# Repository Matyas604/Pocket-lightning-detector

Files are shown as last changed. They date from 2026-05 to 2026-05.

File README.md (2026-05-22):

# Pocket lightning detector
A while back, I was browsing websites with various components and modules when a lightning sensor cought my eye. I was really curious about how it works, so I started researching it. After watching a few Youtube videos 
about this module, I decided I had to try it out. Then I started thinking, and suddenly occurred to me that it would be really cool to create a small, portable, battery-powered device that fits in your pocket and detect 
lightnings. So why not? Why not just design my own PCB and build the entire device myself?

I really enjoyd this project because I tried out a lot of different thigs: studying datasheets and schematics, searching for and creating my own schematic, and designing the PCB and case.

## Features
- The entire device is powered by a **Li-Po** rechargeable battery
- It uses the [**ESP-C3-MINI**](https://documentation.espressif.com/esp32-c3-mini-1_datasheet_en.pdf) as the main microcontroller
- Has **USB-C** port for programming and charging the device
- [**AS3935**](https://www.laskakit.cz/user/related_files/as3935_datasheet.pdf) and **MA5532-AE** for lightning detection
- Detects lightning strikes up to **40 km** away
- Records the distance, energy and current time of lightning strike
- Everything is stored in the internal **RTC memory**, which can store up to 50 lightnings strikes
- Communicates with a mobile via **Bluetooth** to synchronize the time and data
- Has audio feedback when a lightning strike been detected or other thing happened
- Various battery protections, such as **overcharge**, **undercharge**, **over-discharge** and **overvoltage**
- It uses deep sleep mode to get the longest possible battery life

## CAD model
Everything is stored in a case consisting of two parts: a base and a top cover. The top cover is secured with four **M3** screws and heat inserts, along with the **PCB**, which is secured with two screws. The buttons are labeled
with icons for clear identification of their functions. The dimensions are 106 mm in length, 60 mm in width, and 35 mm in height.

<p align="center">
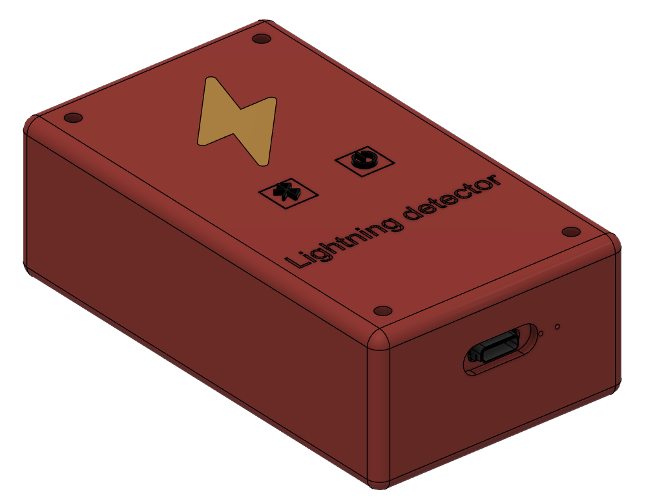
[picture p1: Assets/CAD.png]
CAD model
  
</p>
<p align="center">
  <strong>Made in Fusion360</strong>
</p>

## PCB
It includes two switches: one to turn on and of the device and other to activate **Bluetooth**. In the upper right corner, above the **USB-C** port, are chips for charging, protection, monitoring, and drawing power from the battery, there is also a connector for the battery. The lightning sensor communicates via **I2C**. The pull-up resistors are located under the **ESP-32** near the edge of the **PCB**. The dimensions of **PCB** are 99.7 mm x 35 mm.

<p align="center">
  Schematic
</p>
<p align="center">
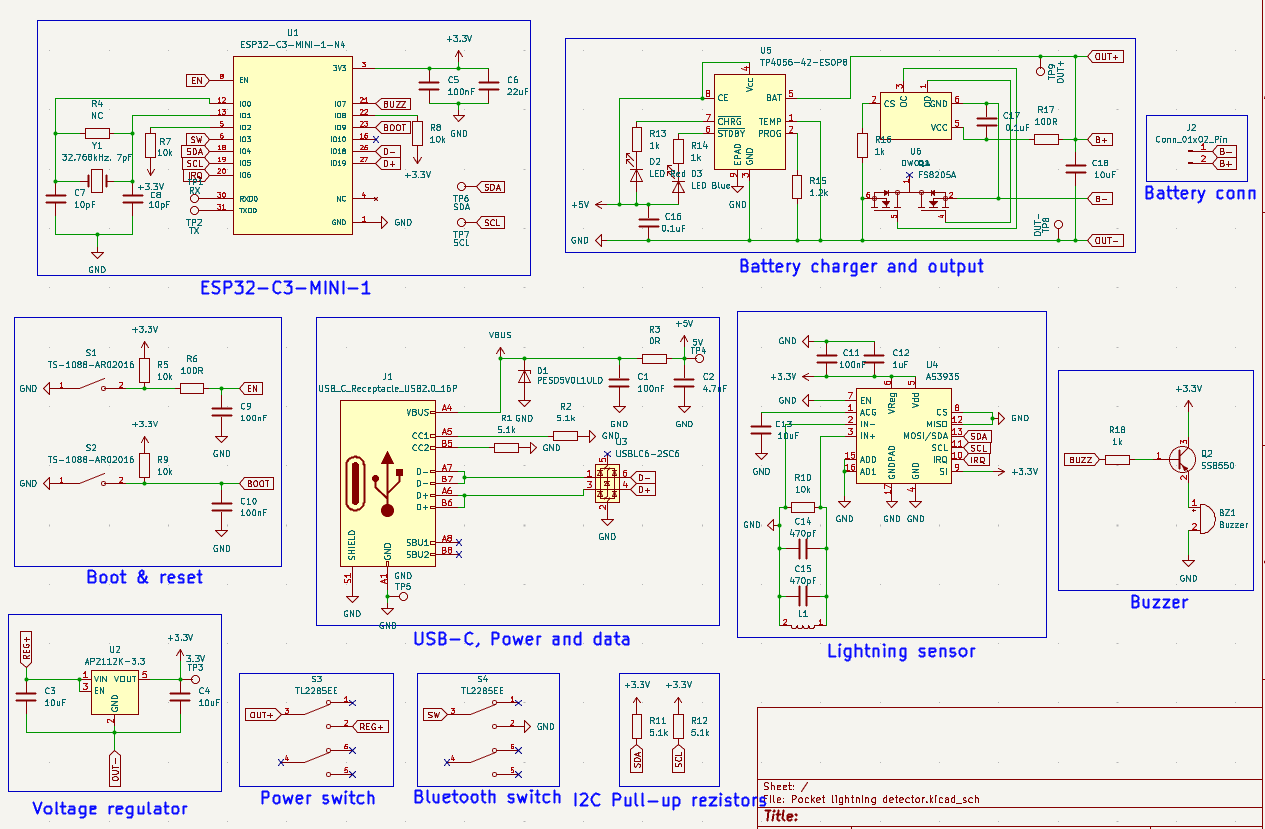
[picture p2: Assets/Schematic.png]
PCB schematic
  
</p>
<p align="center">
  PCB
</p>
<p align="center">
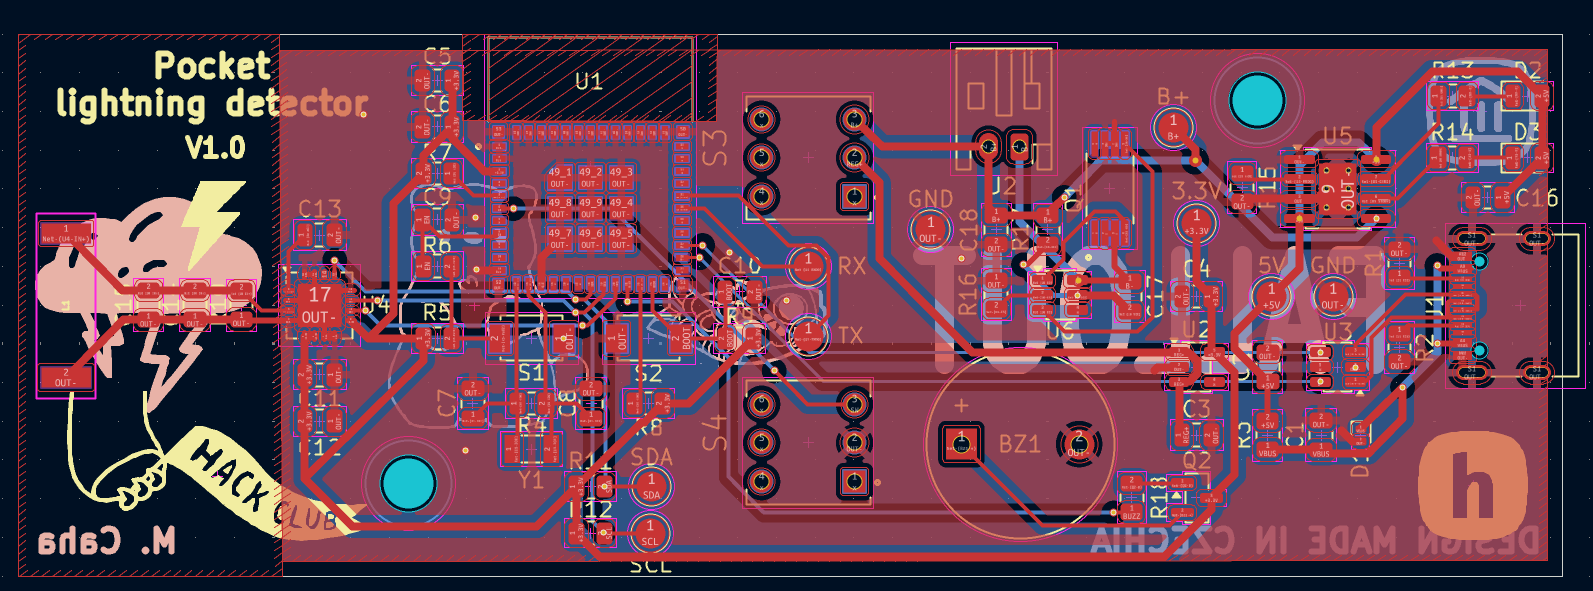
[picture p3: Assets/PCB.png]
  
</p>
<p align="center">
  <strong>Made in KiCad</strong>
</p>
⚠️ The area around the lightning sensor antenna must be kept sufficiently far away from metal parts, as there could interfere with the antenna. For this reason, there si no GND copper area around it, and no screws are located nerby.

## Poster
<p align="center">
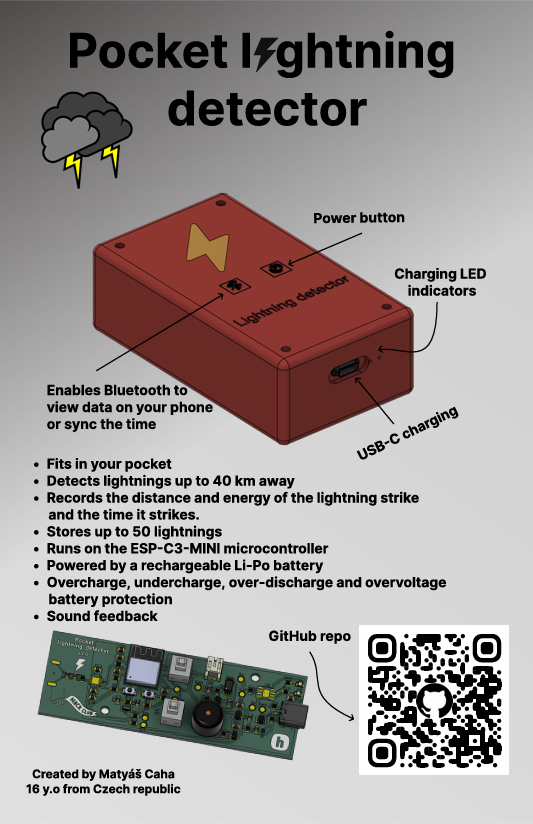
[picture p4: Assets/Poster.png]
  
</p>
<p align="center">
  <strong>Made in Figma</strong>
</p>

## Firmware
It uses standard **C++** code. One button turns the device on, and the other activates **Bluetooth** to display lightnings data and synchronize the time. The time must be synchronized every time the device is turned on. Data cen be currently displayed via a serial monitor application. Once the device is connected, it automatically sends lightning data every 3 seconds. Time is synchronized by sending a command, and the board then retrieves the current time. Lightning strikes and the time are stored in **RTC memory**, so they are erased when the device is turned off. The device runs continuously in deep sleep mode and wakes up only when a lightning strike occurs to save data about the strike and the time it happened, then goes back into deep sleep. **RTC memory** is the only component that remains active even when the device is in deep sleep mode. The **RTC memory** stores a maximum of the last **50 lightning strikes** to prevent it from becoming overloaded. My goal was to maximize battery life, so I chose **Bluetooth** over **Wi-Fi** because **Bluetooth** is much more power-efficient, and I use deep sleep mode as well (Once the device is finished, I’ll carefully measure its battery life).  You can found further details in the comments within the code. After i finished the device, I’ll probably create a nice app where the lightnings will be saved and can be viewed back in time. 

## BOM
You can find it in .csv format [here](https://github.com/Matyas604/Pocket-lightning-detector/blob/main/BOM.csv). 

## License
This project is licensed under the GNU GPL v3.
```
Matyas604/Pocket-lightning-detector - Battery-powered Pocket Lightning Detector
Copyright (C) 2026 Matyáš Caha

This program is free software: you can redistribute it and/or modify
it under the terms of the GNU General Public License as published by
the Free Software Foundation, either version 3 of the License, or
(at your option) any later version.

This program is distributed in the hope that it will be useful,
but WITHOUT ANY WARRANTY; without even the implied warranty of
MERCHANTABILITY or FITNESS FOR A PARTICULAR PURPOSE. See the
GNU General Public License for more details.

You should have received a copy of the GNU General Public License
along with this program. If not, see <https://www.gnu.org/licenses/>.
```

<hr>

<p align="center">
  Made with ❤️ by <a href="https://github.com/Matyas604">@Matyas604</a>
</p>

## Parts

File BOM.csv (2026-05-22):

Item | Qty. | Price (USD) | Link | Distributor
PCB | 1 | 2 | https://jlcpcb.com/ | JLCPCB
Stencil | 1 | 3.05 | https://jlcpcb.com/ | JLCPCB
JLCPCB Shipping | 1 | 11.80 | https://jlcpcb.com/ | JLCPCB
ESP32-C3-MINI-1-N4 | 1 | 3.15 | https://www.lcsc.com/product-detail/C2838502.html | LCSC
CC0805KRX7R9BB104 | 6 | 0.53 | https://www.lcsc.com/product-detail/C49678.html | LCSC
CL21A226KOQNNNE | 1 | 0.6 | https://www.lcsc.com/product-detail/C296720.html | LCSC
GRM21BR71H105KA12L | 1 | 0.77 | https://www.lcsc.com/product-detail/C77083.html | LCSC
GRM21BR61H106KE43L | 4 | 0.69 | https://www.lcsc.com/product-detail/C440198.html | LCSC
VJ0805A471FXACW1BC | 2 | 1.47 | https://www.lcsc.com/product-detail/C1850692.html | LCSC
FRC0805F1002TS | 4 | 0.2 | https://www.lcsc.com/product-detail/C2907219.html | LCSC
FRC0805F1001TS | 4 | 0.2 | https://www.lcsc.com/product-detail/C2907232.html | LCSC
FRC0805F1201TS | 1 | 0.2 | https://www.lcsc.com/product-detail/C2933293.html | LCSC
RC0805FR-07100RL | 2 | 0.27 | https://www.lcsc.com/product-detail/C105577.html | LCSC
0805W8F5101T5E | 4 | 0.27 | https://www.lcsc.com/product-detail/C27834.html | LCSC
0805W8F0000T5E | 1 | 0.23 | https://www.lcsc.com/product-detail/C17477.html | LCSC
USBLC6-2SC6 | 1 | 0.76 | https://www.lcsc.com/product-detail/C7519.html | LCSC
PESD5V0L1ULD | 1 | 0.45 | https://www.lcsc.com/product-detail/C552557.html | LCSC
TYPE-C-31-M-12 | 1 | 0.86 | https://www.lcsc.com/product-detail/C165948.html?s_z=n_C165948 | LCSC
AP2112K-3.3 | 1 | 0.82 | https://www.lcsc.com/product-detail/C51118.html | LCSC
TS-1088-AR02016 | 2 | 0.54 | https://www.lcsc.com/product-detail/C720477.html | LCSC
TP4056-42-ESOP8 | 1 | 0.93 | https://www.lcsc.com/product-detail/C16581.html | LCSC
DW01A | 1 | 0.86 | https://www.lcsc.com/product-detail/C351410.html | LCSC
FS8205A | 1 | 0.47 | https://www.lcsc.com/product-detail/C2830320.html | LCSC
SS8550 | 1 | 0.52 | https://www.lcsc.com/product-detail/C727138.html | LCSC
2.54-1*20P | 1 | 0.69 | https://www.lcsc.com/product-detail/C50981.html | LCSC
S2B-PH-K-S(LF)(SN) | 1 | 0.76 | https://www.lcsc.com/product-detail/C173752.html | LCSC
YLED0805B | 1 | 0.84 | https://www.lcsc.com/product-detail/C19273154.html | LCSC
YLED0805R | 1 | 0.81 | https://www.lcsc.com/product-detail/C19171391.html | LCSC
3131M-32.768DT07NNL | 1 | 0.89 | https://www.lcsc.com/product-detail/C46598421.html | LCSC
VJ0805A100FXACW1BC | 2 | 0.94 | https://www.lcsc.com/product-detail/C2177610.html | LCSC
CL21A475KBQNNNE | 1 | 0.27 | https://www.lcsc.com/product-detail/C98192.html | LCSC
LCSC Shipping | 1 | 10.45 | https://www.lcsc.com/ | LCSC
103040 3.7v 1200mAh Li-ion Battery | 1 | 5.91 | https://www.aliexpress.com/item/1005007995684160.html | AliExpress
Passive Buzzer | 1 | 2.26 | https://www.aliexpress.com/item/1005007144511679.html | AliExpress
Button Switches 8x8 | 2 | 1.97 | https://www.aliexpress.com/item/32874871399.html | AliExpress
M3 4mm | 2 | 2.55 | https://www.aliexpress.com/item/4000981220901.html | AliExpress
M3 6mm | 4 | 2.52 | https://www.aliexpress.com/item/4000981220901.html | AliExpress
M3 heat inserts | 6 | 2.87 | https://www.aliexpress.com/item/1005008666672949.html | AliExpress
3D parts | 5 | 7 | Printing legion | Hack club
AS3935 and MA5532-AE | 1 | 21.83 | https://www.aliexpress.com/item/32828658129.html | AliExpress
AliExpress Shipping | 1 | 1.71 | https://www.aliexpress.com/ | AliExpress

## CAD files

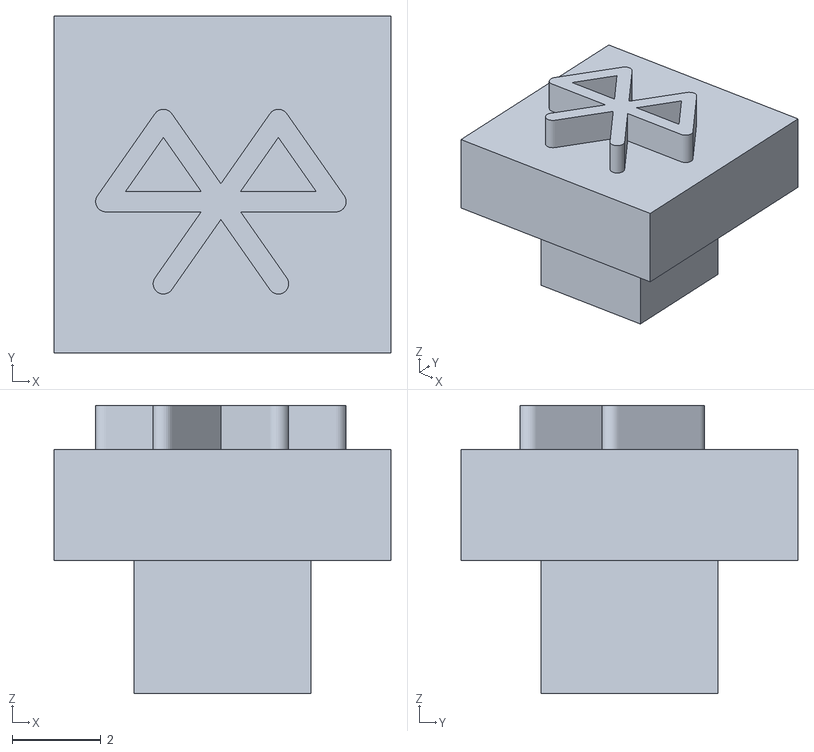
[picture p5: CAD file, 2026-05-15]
Production/3D parts/Bluetooth button cap.stl
7.60 x 7.60 x 6.50

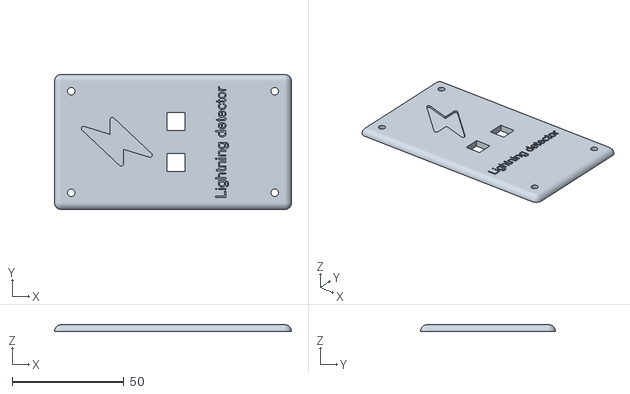
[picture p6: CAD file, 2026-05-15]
Production/3D parts/Top.stl
106.0 x 60.4 x 3.00

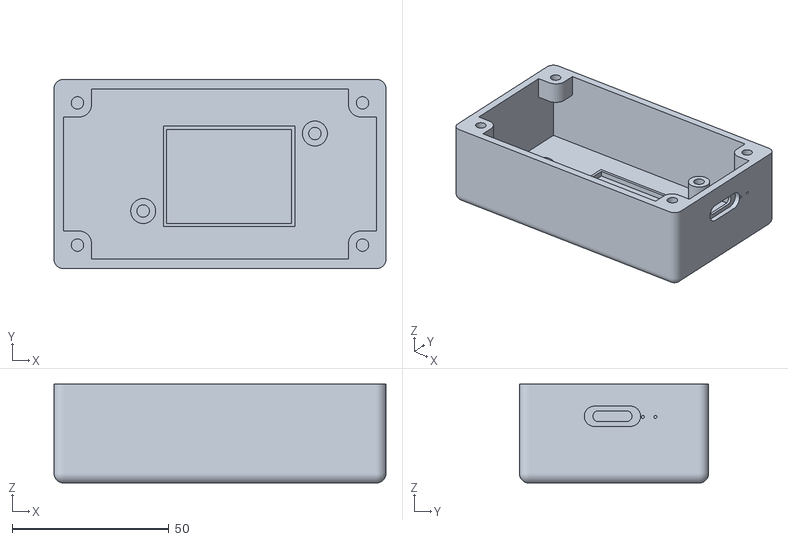
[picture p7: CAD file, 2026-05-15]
Production/3D parts/Bottom.stl
106.0 x 60.4 x 31.6

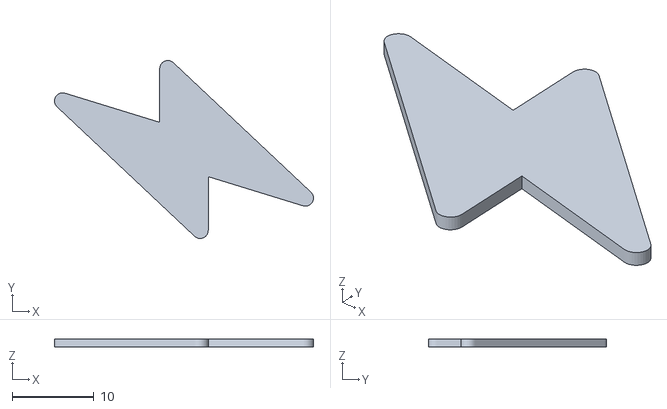
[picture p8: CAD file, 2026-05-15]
Production/3D parts/Lightning.stl
31.8 x 21.8 x 1.00

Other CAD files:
Production/3D parts/Power button cap.stl

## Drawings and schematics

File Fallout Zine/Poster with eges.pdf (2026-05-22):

# Pocket l ghtning

# detector

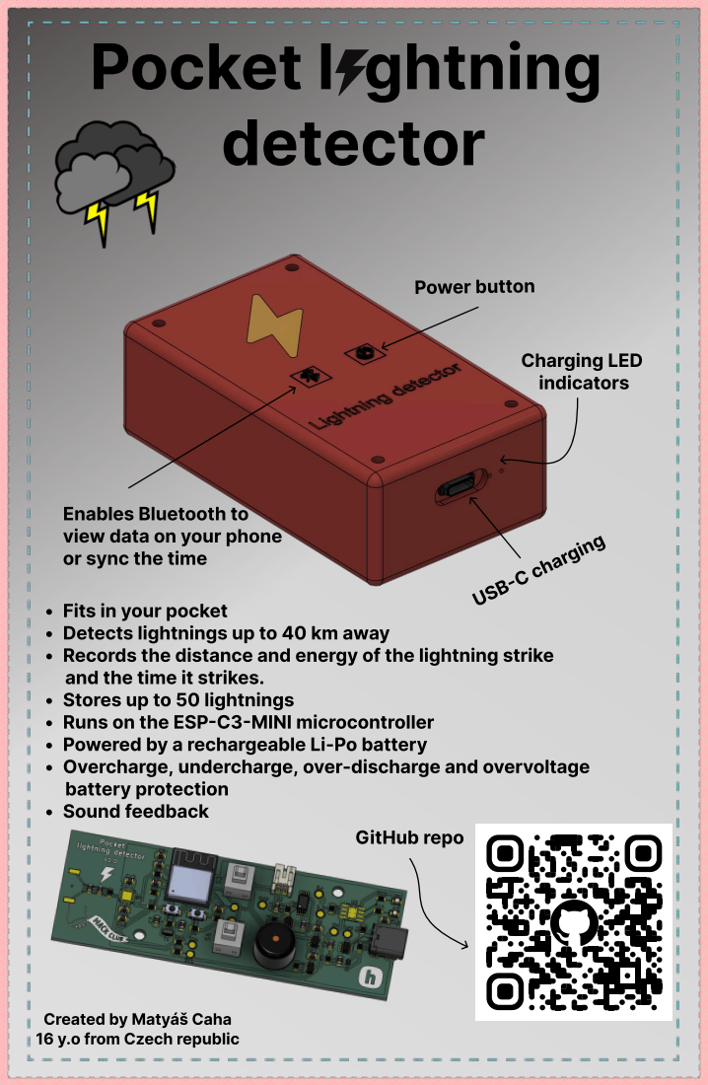
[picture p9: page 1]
Power button; Charging LED; indicators; USB-C charging; GitHub repo

Enables Bluetooth to
view data on your phone
or sync the time

Fits in your pocket
Detects lightnings up to 40 km away
Records the distance and energy of the lightning strike
and the time it strikes.
Stores up to 50 lightnings
Runs on the ESP-C3-MINI microcontroller
Powered by a rechargeable Li-Po battery
Overcharge, undercharge, over-discharge and overvoltage
battery protection
Sound feedback

Created by Matyáš Caha
16 y.o from Czech republic

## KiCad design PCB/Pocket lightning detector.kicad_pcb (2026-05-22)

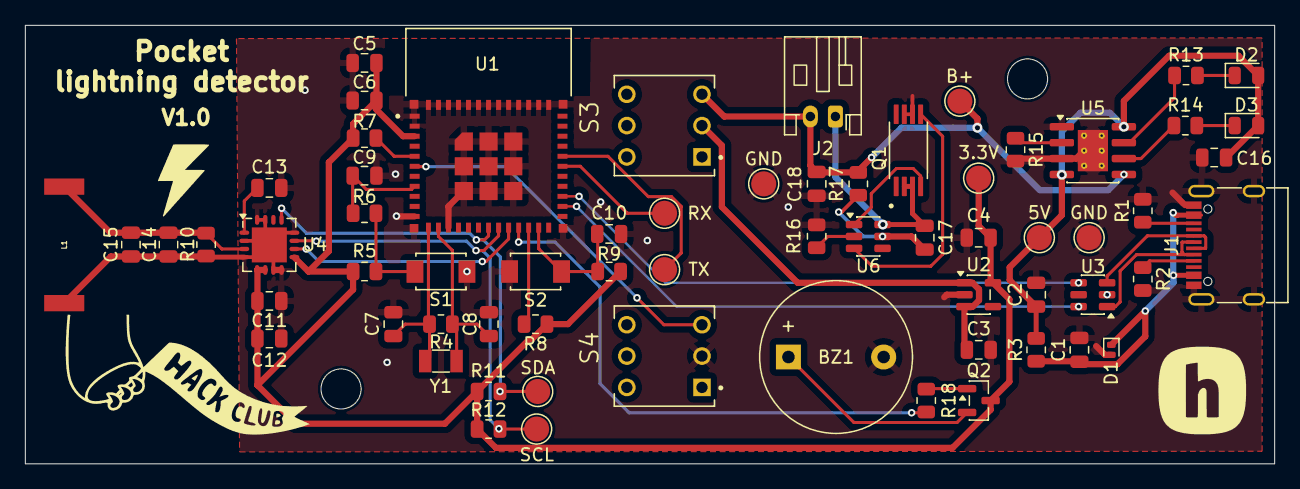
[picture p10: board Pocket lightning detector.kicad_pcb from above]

Board: 2 copper layers, 99.7 x 35.0 mm, 65 parts (0 on the bottom side), 40 nets.

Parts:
3.3V: 3.3V; TestPoint_Pad_D2.0mm
5V: 5V; TestPoint_Pad_D2.0mm
B+: OUT+; TestPoint_Pad_D2.0mm
BZ1: Buzzer; Buzzer_12x9.5RM7.6
C1, C2: 4uF; C_0805_2012Metric
C3, C4: 4.7uF; C_0805_2012Metric
C5, C9, C10, C11: 100nF; C_0805_2012Metric
C6: 22uF; C_0805_2012Metric
C7, C8: TBD; C_0805_2012Metric
C12: 1uF; C_0805_2012Metric
C13, C18: 10uF; C_0805_2012Metric
C14, C15: 470pF; C_0805_2012Metric
C16, C17: 0.1uF; C_0805_2012Metric
D1: PESD5V0L1ULD; D_SOD-882D
D2: LED Red; LED_0805_2012Metric
D3: LED Blue; LED_0805_2012Metric
GND: GND; TestPoint_Pad_D2.0mm
GND#2: OUT-; TestPoint_Pad_D2.0mm
J1: USB_C_Receptacle_USB2.0_16P; USB_C_Receptacle_G-Switch_GT-USB-7010ASV
J2: Conn_01x02_Pin; JST_PH_S2B-PH-K_1x02_P2.00mm_Horizontal
L1: 100uH; MA5532-AE
Q1: FS8205A; SOP65P640X120-8N
Q2: SS8550; SOT-23
R1, R2, R11, R12: 5.1k; R_0805_2012Metric
R3: 0R; R_0805_2012Metric
R4: TBD; R_0805_2012Metric
R5, R7, R8, R9, R10: 10k; R_0805_2012Metric
R6, R17: 100R; R_0805_2012Metric
R13, R14, R16, R18: 1k; R_0805_2012Metric
R15: 1.2k; R_0805_2012Metric
RX: RX; TestPoint_Pad_D2.0mm
S1, S2: TS-1088-AR02016; SW_TS-1088-AR02016
S3, S4: TL2285EE; SW_TL2285EE
SCL: SCL; TestPoint_Pad_D2.0mm
SDA: SDA; TestPoint_Pad_D2.0mm
TX: TX; TestPoint_Pad_D2.0mm
U1: ESP32-C3-MINI-1-N4; XCVR_ESP32-C3-MINI-1-N4
U2: AP2112K-3.3; SOT-23-5
U3: USBLC6-2SC6; SOT-23-6
U4: AS3935; MLPQ-16-1EP_4x4mm_P0.65mm_EP2.8x2.8mm
U5: TP4056-42-ESOP8; SOIC-8-1EP_3.9x4.9mm_P1.27mm_EP2.41x3.3mm_ThermalVias
U6: DW01A; SOT-23-6
Y1: Crystal; Crystal_SMD_3215-2Pin_3.2x1.5mm

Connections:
+3.3V: 3.3V.1, C4.1, C5.1, C6.1, C11.2, C12.2, Q2.3 (C), R5.1, R7.2, R8.2, R9.1, R11.1, R12.1, U1.3 (3V3), U2.5 (VOUT), U4.5 (Vdd), U4.6 (VReg), U4.9 (SI)
+5V: 5V.1, C2.1, C16.1, D2.2 (A), D3.2 (A), R3.2, U5.4 (V_{CC}), U5.8 (CE)
B+: B+.1, C18.1, J2.2, R17.1, S3.3, U5.5 (BAT)
B-: C17.1, J2.1, Q1.2, Q1.3, U6.6 (GND)
BOOT: C10.1, R9.2, S2.2, U1.23 (IO9)
BUZZ: R18.1, U1.21 (IO7)
D+: U1.27 (IO19), U3.4 (I/O2)
D-: U1.26 (IO18), U3.6 (I/O1)
EN: C9.1, R6.1, U1.8 (EN)
IRQ: U1.20 (IO6), U4.10 (IRQ)
unnamed: BZ1.1 (+), Q2.2 (E)
unnamed: D2.1 (K), R13.2
unnamed: D3.1 (K), R14.2
unnamed: J1.A5 (CC1), R2.1
unnamed: J1.B5 (CC2), R1.1
unnamed: J1.A6 (D+), J1.B6 (D+), U3.3 (I/O2)
unnamed: J1.A7 (D-), J1.B7 (D-), U3.1 (I/O1)
unnamed: Q2.1 (B), R18.2
unnamed: R5.2, R6.2, S1.2
unnamed: C7.1, R4.1, U1.12 (IO0), Y1.1
unnamed: C8.1, R4.2, U1.13 (IO1), Y1.2
unnamed: R7.1, U1.5 (IO2)
unnamed: R8.1, U1.22 (IO8)
unnamed: RX.1, U1.30 (RXD0)
unnamed: TX.1, U1.31 (TXD0)
unnamed: C13.1, U4.1 (ACG)
unnamed: C14.2, C15.2, L1.1, R10.2, U4.3 (IN+)
unnamed: R15.1, U5.2 (PROG)
unnamed: R13.1, U5.7 (~CHRG)
unnamed: R14.1, U5.6 (~STDBY)
unnamed: R16.2, U6.2 (CS)
unnamed: Q1.5, U6.3 (OC)
unnamed: Q1.4, U6.1 (OD)
unnamed: C17.2, R17.2, U6.5 (VCC)
OUT-: BZ1.2 (-), C1.2, C2.2, C3.2, C4.2, C5.2, C6.2, C7.2, C8.2, C9.2, C10.2, C11.1, C12.1, C13.2, C14.1, C15.1, C16.2, C18.2, D1.2 (A), GND.1, GND#2.1, J1.A1 (GND), J1.A12 (GND), J1.B1 (GND), J1.B12 (GND), J1.S1 (SHIELD), L1.2, Q1.6, Q1.7, R1.2, R2.2, R10.1, R15.2, R16.1, S1.1, S2.1, S4.2, U1.1 (GND), U1.2 (GND), U1.11 (GND), U1.14 (GND), U1.36 (GND), U1.37 (GND), U1.38 (GND), U1.39 (GND), U1.40 (GND), U1.41 (GND), U1.42 (GND), U1.43 (GND), U1.44 (GND), U1.45 (GND), U1.46 (GND), U1.47 (GND), U1.48 (GND), U1.49_1 (GND), U1.49_2 (GND), U1.49_3 (GND), U1.49_4 (GND), U1.49_5 (GND), U1.49_6 (GND), U1.49_7 (GND), U1.49_8 (GND), U1.49_9 (GND), U1.50 (GND), U1.51 (GND), U1.52 (GND), U1.53 (GND), U2.2 (GND), U3.2 (GND), U4.2 (IN-), U4.4 (GND), U4.7 (EN), U4.8 (CS), U4.12 (MISO), U4.15 (AD0), U4.16 (AD1), U4.17 (GNDPAD), U5.1 (TEMP), U5.3 (GND), U5.9 (EPAD)
REG+: C3.1, S3.2, U2.1 (VIN), U2.3 (EN)
SCL: R12.2, SCL.1, U1.19 (IO5), U4.11 (SCL)
SDA: R11.2, SDA.1, U1.18 (IO4), U4.13 (MOSI/SDA)
SW: S4.3, U1.6 (IO3)
VBUS: C1.1, D1.1 (K), J1.A4 (VBUS), J1.A9 (VBUS), J1.B4 (VBUS), J1.B9 (VBUS), R3.1

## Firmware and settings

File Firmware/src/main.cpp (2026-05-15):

#include <Arduino.h> 
#include <Wire.h> // Include the Wire library for I2C communication
#include <SparkFun_AS3935.h> // Include the AS3935 library for lightning sensor
#include <BLEDevice.h> // Include the BLE library
#include <BLEServer.h> // Include the BLE Server library
#include <BLEUtils.h> // Include the BLE Utils library
#include <BLE2902.h> // Include the BLE Descriptor library
#include <time.h> // Include time library for timestamping lightning events
#include <sys/time.h> 
#include <esp_attr.h> // Include ESP32 attributes for RTC memory

// Pin definitions
#define PIN_SDA 4 //Pin for I2C SDA
#define PIN_SCL 5 //Pin for I2C SCL
#define PIN_IRQ 2 //Pin for AS3935 IRQ output
#define BT_SWITCH_PIN 3 //Switch to toggle Bluetooth
#define BUZZER_PIN 7 //Pin for buzzer

// Function prototypes
void runBluetoothMode();
void goToSleep();
void processLightning();

// Lightning event structure
struct LightningEvent {
  time_t timestamp;
  uint8_t distance;
  uint32_t energy;
};

// Store lightning events in RTC memory
RTC_DATA_ATTR LightningEvent history[50]; // Store up to 50 lightning events
RTC_DATA_ATTR int eventCount = 0;

// Initialize AS3935 lightning sensor and BLE server
SparkFun_AS3935 Lightning;
BLECharacteristic *pCharacteristic;
bool deviceConnected = false;

// Buzzer functions
void beep(int frequency, int duration) {
  tone(BUZZER_PIN, frequency, duration);
  delay(duration);
  noTone(BUZZER_PIN);
}

// Alert function for lightning events
void alertLightning() {
  beep(2500, 100);
  delay(50);
  beep(2500, 100);
}

// Process lightning events
void processLightning() {
  uint8_t interuptSource = Lightning.readInterruptReg(); // Read the interrupt source from the AS3935

  if (interuptSource == 0x08) { // Lightning detected
    uint8_t distance = Lightning.distanceToStorm(); // Distance in km
    uint32_t energy = Lightning.lightningEnergy(); // Energy of the lightning

    if (eventCount < 50) { // Store the lightning event in RTC memory
      history[eventCount] = {time(NULL), distance, energy};
      eventCount++;
    }
    alertLightning();
  }
}

// BLE server callbacks
class MyServerCallbacks : public BLEServerCallbacks {
  void onConnect(BLEServer* pServer) {
    deviceConnected = true;
    beep(1500, 300); // Beep on connection
  }
  void onDisconnect(BLEServer* pServer) { 
    deviceConnected = false;
    BLEDevice::startAdvertising();
  }
};

// BLE characteristic callbacks
class MyCharacteristicCallbacks : public BLECharacteristicCallbacks {
  void onWrite(BLECharacteristic *pCharacteristic) {
    std::string rxValue = pCharacteristic->getValue(); 
    if (rxValue.length() > 0 && rxValue[0] == 'T') {
      String timestampStr = "";
      for (size_t i = 1; i < rxValue.length(); i++) timestampStr += rxValue[i]; 

      struct timeval tv = { .tv_sec = (time_t)timestampStr.toInt() }; // Convert the received timestamp string to time_t and set the system time
      settimeofday(&tv, NULL);
      beep(2000, 50); // Beep on time sync
    }
  }
};

// Setup function
void setup() {
  pinMode(BUZZER_PIN, OUTPUT); // Set buzzer pin as output
  pinMode(BT_SWITCH_PIN, INPUT_PULLUP); // Set Bluetooth switch pin as input
  pinMode(PIN_IRQ, INPUT); // Set AS3935 IRQ pin as input

  Wire.begin(PIN_SDA, PIN_SCL); // Initialize I2C communication

  if (!Lightning.begin()) { 
    beep(500, 1000); // Beep on initialization failure
  }

  esp_sleep_wakeup_cause_t wakeup_reason = esp_sleep_get_wakeup_cause();

  if (wakeup_reason == ESP_SLEEP_WAKEUP_GPIO) {
    processLightning();
  } else if (wakeup_reason == ESP_SLEEP_WAKEUP_UNDEFINED) {
    beep(3000, 50); // Beep on undefined wakeup
  }

// Checks the Bluetooth switch state and either run Bluetooth mode or go to sleep
  if (digitalRead(BT_SWITCH_PIN) == LOW) {
    runBluetoothMode();
  } else {
    goToSleep();
  }
}

// Bluetooth mode function
void runBluetoothMode() {
  BLEDevice::init("Lightning Detector"); // Bluetooth device name
  BLEServer *pServer = BLEDevice::createServer();
  pServer->setCallbacks(new MyServerCallbacks());

  BLEService *pService = pServer->createService("4fafc201-1fb5-459e-8fcc-c5c9c331914b");
  pCharacteristic = pService->createCharacteristic(
                      "beb5483e-36e1-4688-b7f5-ea07361b26a8",
                      BLECharacteristic::PROPERTY_READ | BLECharacteristic::PROPERTY_WRITE |
                      BLECharacteristic::PROPERTY_NOTIFY
                    );

  pCharacteristic->setCallbacks(new MyCharacteristicCallbacks());
  pCharacteristic->addDescriptor(new BLE2902());
  pService->start();
  pServer->getAdvertising()->start();

  // Sends lightning event history every 3 seconds if a device is connected
  while (digitalRead(BT_SWITCH_PIN) == LOW) {
    if (deviceConnected) {
      String dataOut = "LIGHTNINGS:\n";
      if (eventCount == 0) {
        dataOut += "There are no lightnings yet.";
      } else {
        for (int i = 0; i < eventCount; i++) {
          struct tm *tm_info = localtime(&history[i].timestamp);
          char timeBuf[20];
          strftime(timeBuf, 20, "%H:%M:%S", tm_info);
          dataOut += String(timeBuf) + " | " + String(history[i].distance) + "km | " + String(history[i].energy) + "\n";
        }
      }
      pCharacteristic->setValue(dataOut.c_str());
      pCharacteristic->notify();
    }
    delay(3000);
  }
  goToSleep();
}

// Function to put the ESP32 into deep sleep mode
void goToSleep() {
  esp_deep_sleep_enable_gpio_wakeup(1 << PIN_IRQ, ESP_GPIO_WAKEUP_GPIO_HIGH); // Wake up on logic high of the lightning sensor's IRQ pin
  esp_deep_sleep_start(); 
}

// Loop function (not used in this project)
void loop() {
}

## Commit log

2026-05-15 Adding files
    [Bluetooth button cap.stl, Bottom.stl, Lightning.stl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]
2026-05-16 Add BOM.csv with initial component list
    [BOM.csv]
2026-05-17 BOM components update
    [BOM.csv]
2026-05-17 BOM fix
    [BOM.csv]
2026-05-17 Final BOM fix
    [BOM.csv]
2026-05-22 Final fix schematic
2026-05-22 Final CAD
2026-05-22 BOM done!
    [BOM.csv]
2026-05-22 Fixing PCB
    [Pocket lightning detector.kicad_pcb, Pocket lightning detector.kicad_sch]
